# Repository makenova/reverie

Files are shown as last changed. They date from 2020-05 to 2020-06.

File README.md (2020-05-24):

# Reverie
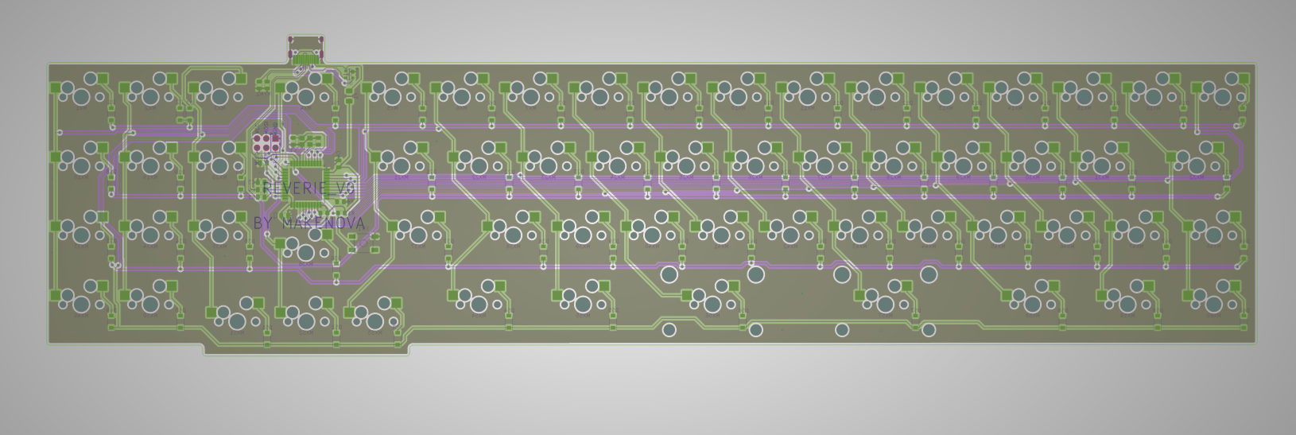
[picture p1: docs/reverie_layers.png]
tracespace back


The reverie is a hot swap mini 1800 inspired by the [Elongate](https://geekhack.org/index.php?topic=106527), [Clarabelle](https://geekhack.org/index.php?topic=106380.0), and [Garbage Truck](https://www.reddit.com/r/MechanicalKeyboards/comments/gkb4nt/the_garbage_truck/) keyboards.
I made this because hot swap is usually left out in smaller runs of high end coustoms.

The plate file can be found in the [docs](./docs) folder.

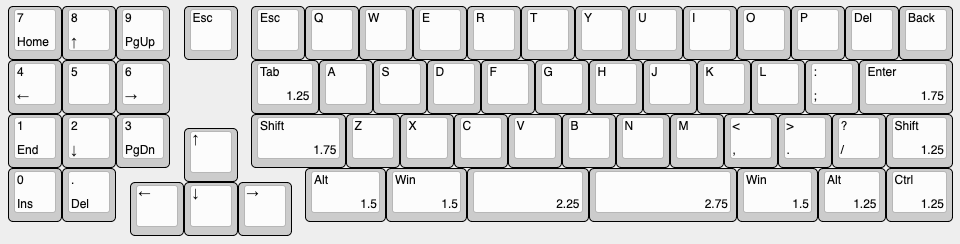
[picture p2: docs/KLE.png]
KLE Diagram


## Wiring Guide

The following diagram displays the colums and rows.

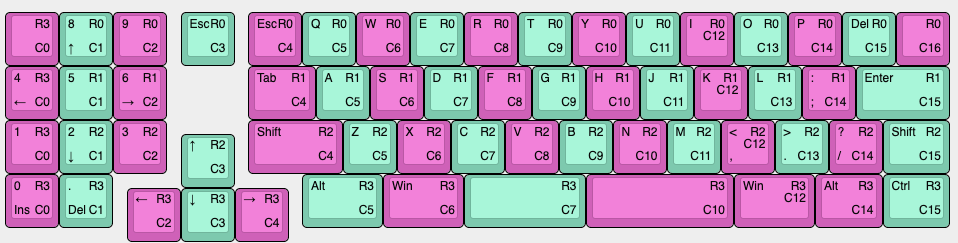
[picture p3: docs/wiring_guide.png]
Wiring Guide


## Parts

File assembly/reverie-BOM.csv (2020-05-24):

Designator | Quantity | Value | Footprint | LCSC Part #
C1, C2, | 2 | 22pF | 0805 | C1804
C3, | 1 | 1uF | 0805 | C28323
C4, C5, C6, | 3 | 0.1uF | 0805 | C49678
C7, | 1 | 10uF | 0805 | C15850
D1, D2, D3, D4, D5, D6, D7, D8, D9, D10, D11, D12, D13, D14, D15, D16, D17, D18, D19, D20, D21, D22, D23, D24, D25, D26, D27, D28, D29, D30, D31, D32, D33, D34, D35, D37, D38, D39, D40, D41, D42, D43, D44, D45, D46, D47, D48, D36, D49, D50, D51, D53, D54, D55, D56, D57, D58, D59, D60, D52, | 60 | D_Small | SOD-123 | C81598
F1, | 1 | Polyfuse_Small | 1206 | C151162
R2, R7, | 2 | 5.1k | 0805 | C27834
R3, R4, | 2 | 22 | 0805 | C17561
R8, R1, | 2 | 10k | 0805 | C17414
SW1, | 1 | SW_Push | :SMD-SW-4_5.1x5.1x1.5 | C318884
U1, | 1 | PRTR5V0U2X | :SOT-143 | C78442
U2, | 1 | ATmega32U4-AU | QFP-44_10.0x10.0x0.8P | C44854
Y1, | 1 | 16MHz | SMD-3225_4P | C13738

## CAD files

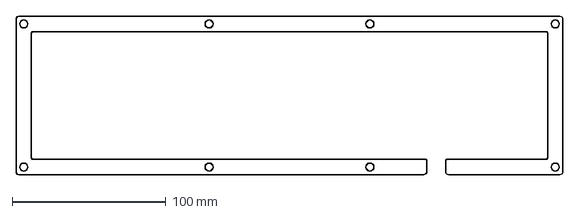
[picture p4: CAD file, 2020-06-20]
case/layer6.dxf
355.4 x 103.0 mm

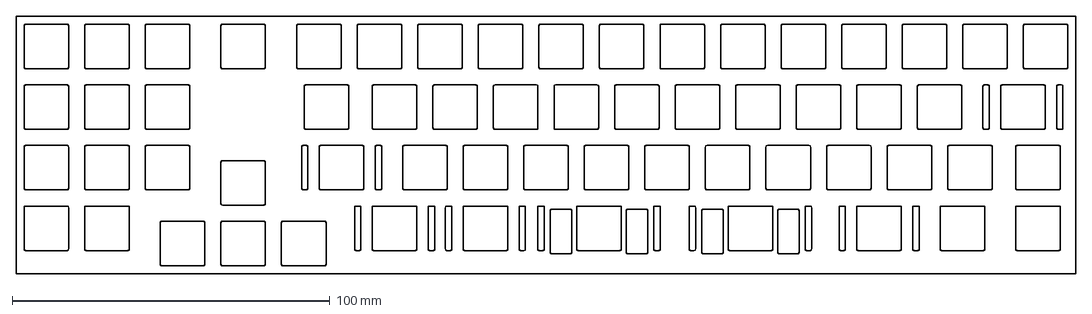
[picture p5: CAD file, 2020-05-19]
docs/plate-20200518-191525.dxf
333.4 x 81.0 mm

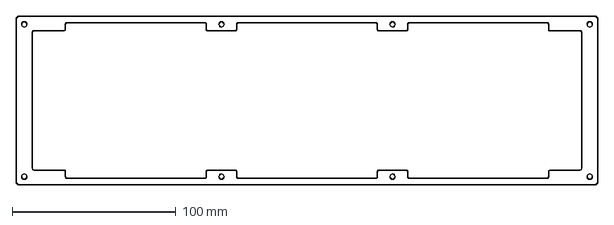
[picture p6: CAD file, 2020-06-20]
case/layer3.dxf
355.4 x 103.0 mm

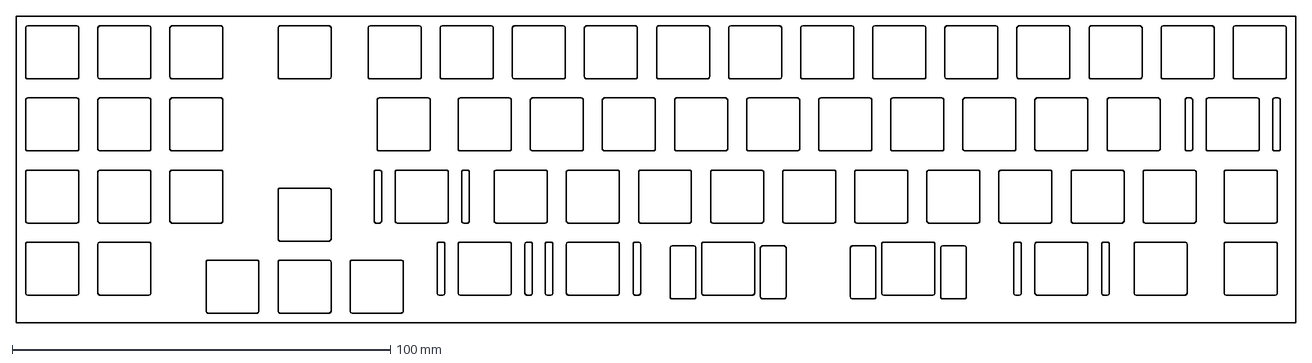
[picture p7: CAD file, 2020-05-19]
docs/plate-20200517-042934.dxf
338.1 x 81.0 mm

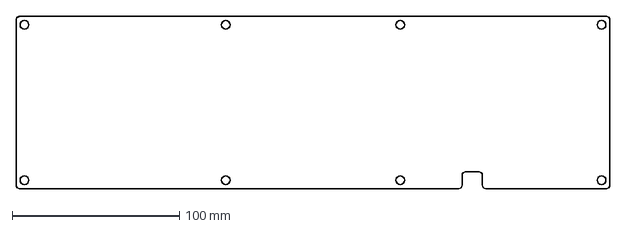
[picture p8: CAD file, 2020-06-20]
case/layer7.dxf
355.4 x 103.0 mm

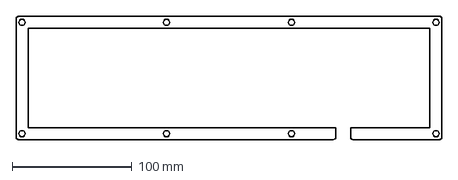
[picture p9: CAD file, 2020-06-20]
case/layer5.dxf
355.4 x 103.0 mm

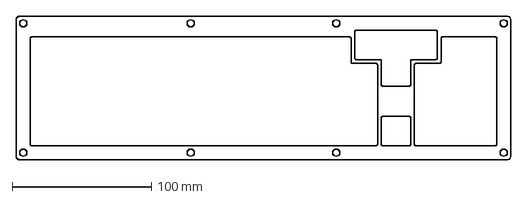
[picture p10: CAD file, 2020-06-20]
case/layer1.dxf
355.4 x 103.0 mm

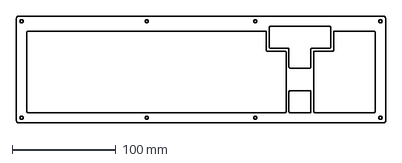
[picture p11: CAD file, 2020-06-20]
case/layer2.dxf
355.4 x 103.0 mm

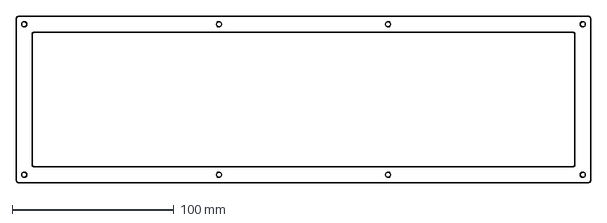
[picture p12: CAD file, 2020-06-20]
case/layer4.dxf
355.4 x 103.0 mm

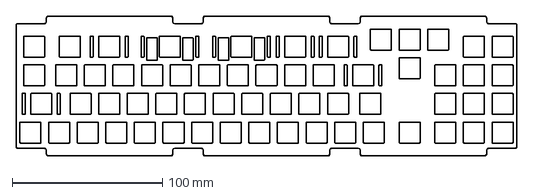
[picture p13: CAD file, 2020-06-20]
case/plate.dxf
333.4 x 93.1 mm

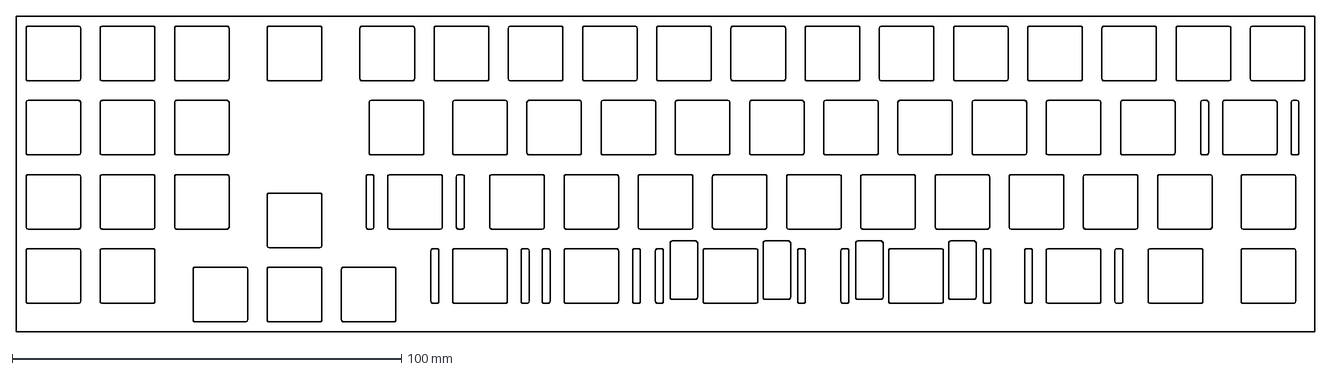
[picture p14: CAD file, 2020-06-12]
case/plate-20200612-134634.dxf
333.4 x 81.0 mm

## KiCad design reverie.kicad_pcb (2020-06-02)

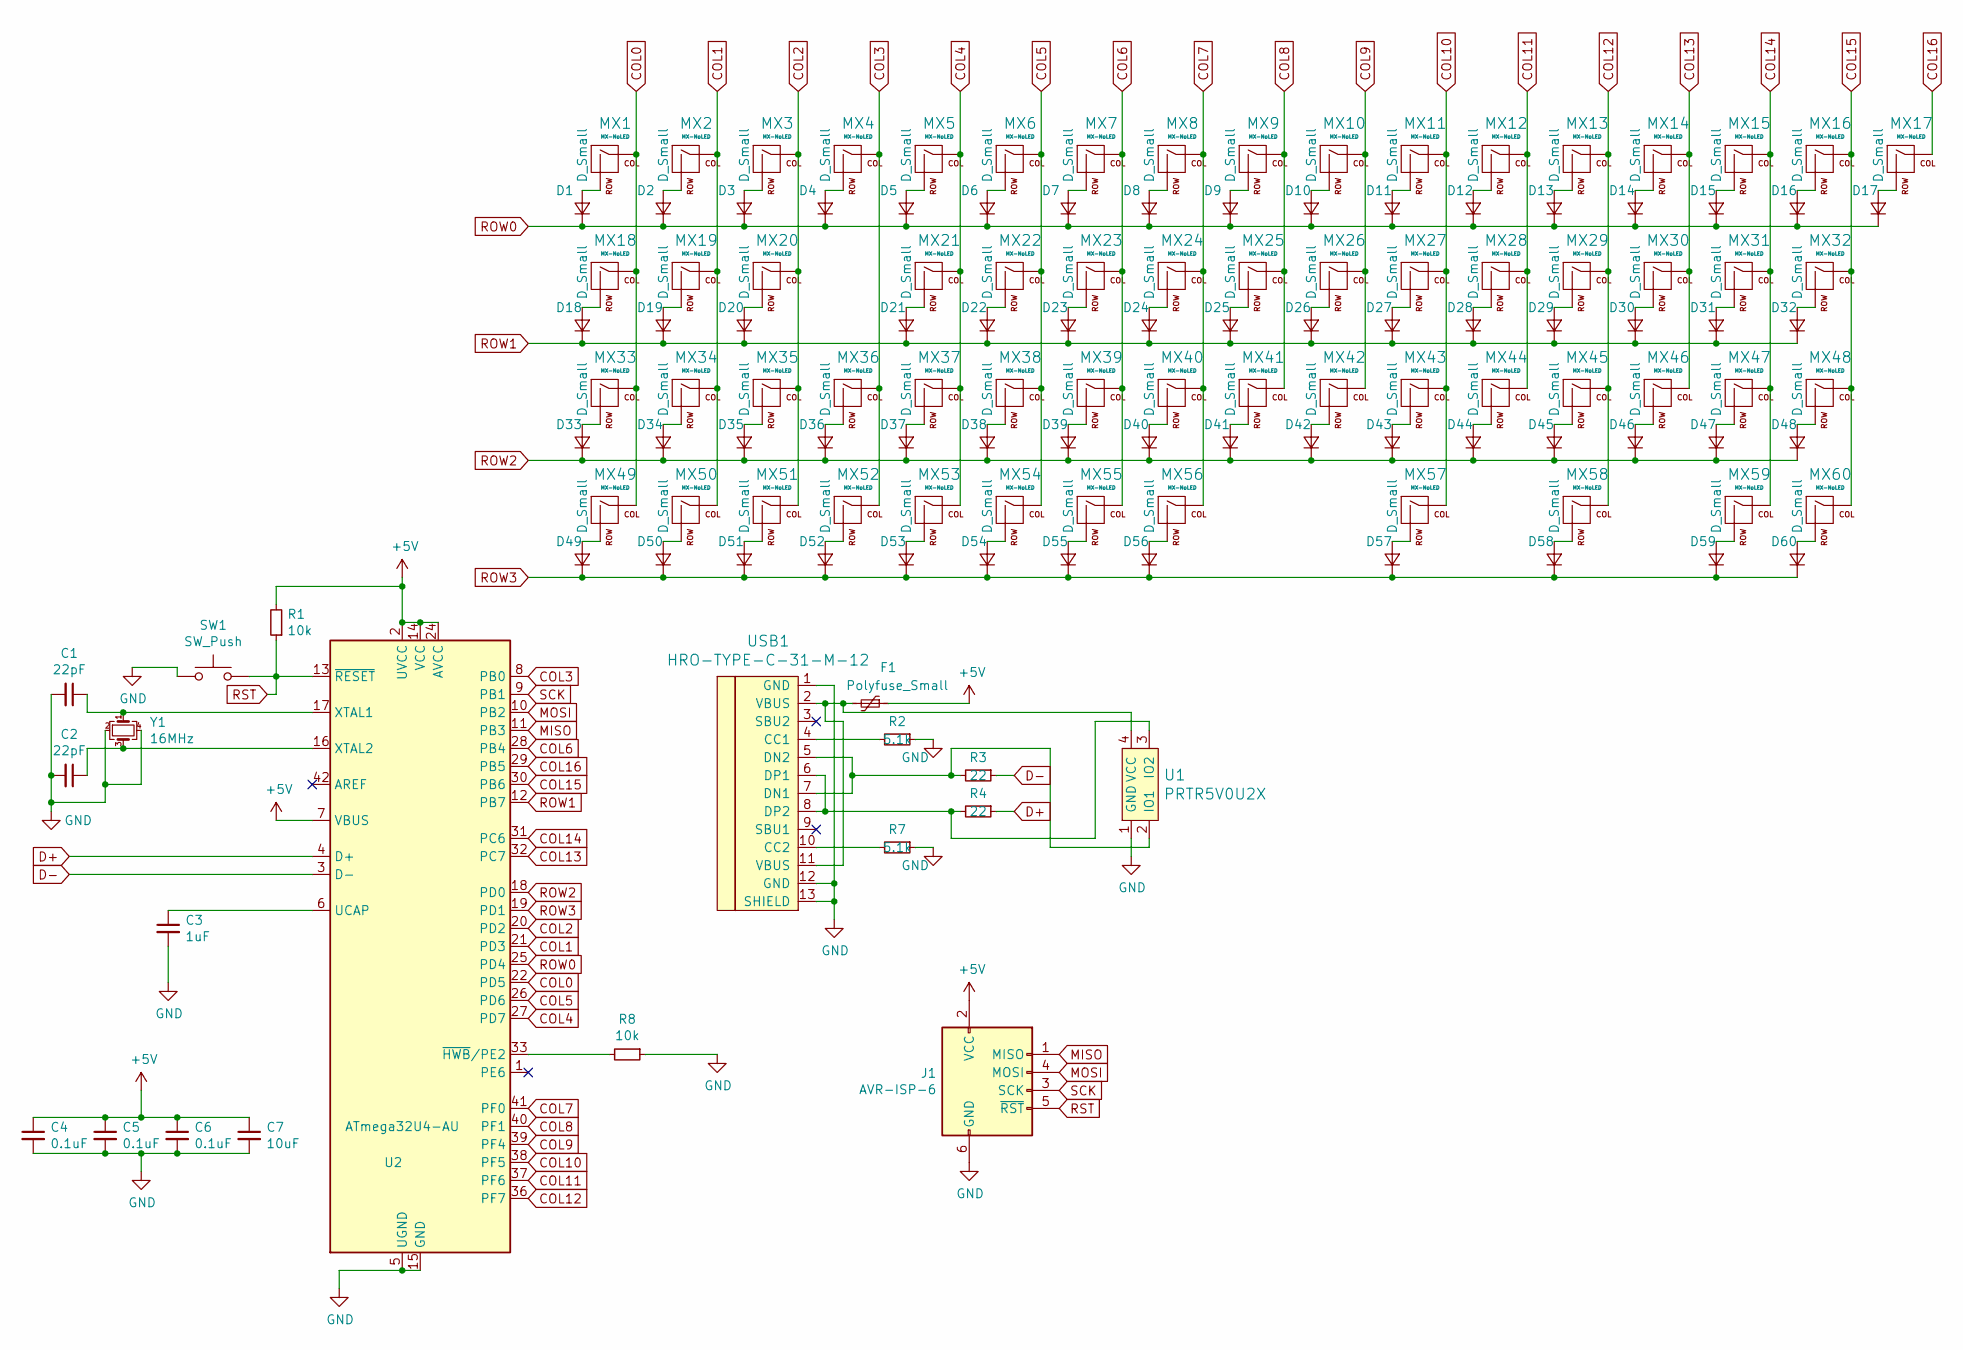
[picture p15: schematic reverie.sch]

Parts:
C1, C2: 22pF; C_0805_2012Metric
C3: 1uF; C_0805_2012Metric
C4, C5, C6: 0.1uF; C_0805_2012Metric
C7: 10uF; C_0805_2012Metric
D1, D2, D3, D4, D5, D6, D7, D8, D9, D10, D11, D12, D13, D14, D15, D16, D17, D18, D19, D20, D21, D22, D23, D24, D25, D26, D27, D28, D29, D30, D31, D32, D33, D34, D35, D36, D37, D38, D39, D40, D41, D42, D43, D44, D45, D46, D47, D48, D49, D50, D51, D52, D53, D54, D55, D56, D57, D58, D59, D60: D_Small; D_SOD-123
F1: Polyfuse_Small; Fuse_1206_3216Metric
J1: AVR-ISP-6; Reset_Pretty-Mask
MX1, MX2, MX3, MX4, MX5, MX6, MX7, MX8, MX9, MX10, MX11, MX12, MX13, MX14, MX15, MX16, MX17, MX18, MX19, MX20, MX22, MX23, MX24, MX25, MX26, MX27, MX28, MX29, MX30, MX31, MX33, MX34, MX35, MX36, MX38, MX39, MX40, MX41, MX42, MX43, MX44, MX45, MX46, MX47, MX49, MX50, MX51, MX52, MX53: MX-NoLED; MXOnly-1U-Hotswap
MX21, MX48, MX59, MX60: MX-NoLED; MXOnly-1.25U-Hotswap
MX32, MX37: MX-NoLED; MXOnly-1.75U-Hotswap
MX54, MX55, MX58: MX-NoLED; MXOnly-1.5U-Hotswap
MX56: MX-NoLED; MXOnly-2.25U-Hotswap-ReversedStabilizers
MX57: MX-NoLED; MXOnly-2.75U-Hotswap-ReversedStabilizers
R1, R8: 10k; R_0805_2012Metric
R2, R7: 5.1k; R_0805_2012Metric
R3, R4: 22; R_0805_2012Metric
SW1: SW_Push; SKQG-1155865
U1: PRTR5V0U2X; SOT143B
U2: ATmega32U4-AU; TQFP-44_10x10mm_P0.8mm
USB1: HRO-TYPE-C-31-M-12; HRO-TYPE-C-31-M-12-HandSoldering
Y1: 16MHz; Crystal_SMD_3225-4Pin_3.2x2.5mm

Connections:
+5V: C4.1, C5.1, C6.1, C7.1, F1.1, J1.2 (VCC), R1.2, U2.2 (UVCC), U2.7 (VBUS), U2.14 (VCC), U2.24 (AVCC), U2.34 (VCC), U2.44 (AVCC)
COL0: MX1.1 (COL), MX18.1 (COL), MX33.1 (COL), MX49.1 (COL), U2.22 (PD5)
COL1: MX2.1 (COL), MX19.1 (COL), MX34.1 (COL), MX50.1 (COL), U2.21 (PD3)
COL2: MX3.1 (COL), MX20.1 (COL), MX35.1 (COL), MX51.1 (COL), U2.20 (PD2)
COL3: MX4.1 (COL), MX36.1 (COL), MX52.1 (COL), U2.8 (PB0)
COL4: MX5.1 (COL), MX21.1 (COL), MX37.1 (COL), MX53.1 (COL), U2.27 (PD7)
COL5: MX6.1 (COL), MX22.1 (COL), MX38.1 (COL), MX54.1 (COL), U2.26 (PD6)
COL6: MX7.1 (COL), MX23.1 (COL), MX39.1 (COL), MX55.1 (COL), U2.28 (PB4)
COL7: MX8.1 (COL), MX24.1 (COL), MX40.1 (COL), MX56.1 (COL), U2.41 (PF0)
COL8: MX9.1 (COL), MX25.1 (COL), MX41.1 (COL), U2.40 (PF1)
COL9: MX10.1 (COL), MX26.1 (COL), MX42.1 (COL), U2.39 (PF4)
COL10: MX11.1 (COL), MX27.1 (COL), MX43.1 (COL), MX57.1 (COL), U2.38 (PF5)
COL11: MX12.1 (COL), MX28.1 (COL), MX44.1 (COL), U2.37 (PF6)
COL12: MX13.1 (COL), MX29.1 (COL), MX45.1 (COL), MX58.1 (COL), U2.36 (PF7)
COL13: MX14.1 (COL), MX30.1 (COL), MX46.1 (COL), U2.32 (PC7)
COL14: MX15.1 (COL), MX31.1 (COL), MX47.1 (COL), MX59.1 (COL), U2.31 (PC6)
COL15: MX16.1 (COL), MX32.1 (COL), MX48.1 (COL), MX60.1 (COL), U2.30 (PB6)
COL16: MX17.1 (COL), U2.29 (PB5)
D+: R4.1, U2.4 (D+)
D-: R3.1, U2.3 (D-)
GND: C1.2, C2.2, C3.2, C4.2, C5.2, C6.2, C7.2, J1.6 (GND), R2.1, R7.1, R8.1, SW1.1, U1.1 (GND), U2.5 (UGND), U2.15 (GND), U2.23 (GND), U2.35 (GND), U2.43 (GND), USB1.1 (GND), USB1.12 (GND), USB1.13 (SHIELD), Y1.2, Y1.4
MISO: J1.1 (MISO), U2.11 (PB3)
MOSI: J1.4 (MOSI), U2.10 (PB2)
unnamed: C1.1, U2.17 (XTAL1), Y1.1
unnamed: C2.1, U2.16 (XTAL2), Y1.3
unnamed: C3.1, U2.6 (UCAP)
unnamed: D1.2 (A), MX1.2 (ROW)
unnamed: D2.2 (A), MX2.2 (ROW)
unnamed: D3.2 (A), MX3.2 (ROW)
unnamed: D4.2 (A), MX4.2 (ROW)
unnamed: D5.2 (A), MX5.2 (ROW)
unnamed: D6.2 (A), MX6.2 (ROW)
unnamed: D7.2 (A), MX7.2 (ROW)
unnamed: D8.2 (A), MX8.2 (ROW)
unnamed: D9.2 (A), MX9.2 (ROW)
unnamed: D10.2 (A), MX10.2 (ROW)
unnamed: D11.2 (A), MX11.2 (ROW)
unnamed: D12.2 (A), MX12.2 (ROW)
unnamed: D13.2 (A), MX13.2 (ROW)
unnamed: D14.2 (A), MX14.2 (ROW)
unnamed: D15.2 (A), MX15.2 (ROW)
unnamed: D16.2 (A), MX16.2 (ROW)
unnamed: D17.2 (A), MX17.2 (ROW)
unnamed: D18.2 (A), MX18.2 (ROW)
unnamed: D19.2 (A), MX19.2 (ROW)
unnamed: D20.2 (A), MX20.2 (ROW)
unnamed: D21.2 (A), MX21.2 (ROW)
unnamed: D22.2 (A), MX22.2 (ROW)
unnamed: D23.2 (A), MX23.2 (ROW)
unnamed: D24.2 (A), MX24.2 (ROW)
unnamed: D25.2 (A), MX25.2 (ROW)
unnamed: D26.2 (A), MX26.2 (ROW)
unnamed: D27.2 (A), MX27.2 (ROW)
unnamed: D28.2 (A), MX28.2 (ROW)
unnamed: D29.2 (A), MX29.2 (ROW)
unnamed: D30.2 (A), MX30.2 (ROW)
unnamed: D31.2 (A), MX31.2 (ROW)
unnamed: D32.2 (A), MX32.2 (ROW)
unnamed: D33.2 (A), MX33.2 (ROW)
unnamed: D34.2 (A), MX34.2 (ROW)
unnamed: D35.2 (A), MX35.2 (ROW)
unnamed: D36.2 (A), MX36.2 (ROW)
unnamed: D37.2 (A), MX37.2 (ROW)
unnamed: D38.2 (A), MX38.2 (ROW)
unnamed: D39.2 (A), MX39.2 (ROW)
unnamed: D40.2 (A), MX40.2 (ROW)
unnamed: D41.2 (A), MX41.2 (ROW)
unnamed: D42.2 (A), MX42.2 (ROW)
unnamed: D43.2 (A), MX43.2 (ROW)
unnamed: D44.2 (A), MX44.2 (ROW)
unnamed: D45.2 (A), MX45.2 (ROW)
unnamed: D46.2 (A), MX46.2 (ROW)
unnamed: D47.2 (A), MX47.2 (ROW)
unnamed: D48.2 (A), MX48.2 (ROW)
unnamed: D49.2 (A), MX49.2 (ROW)
unnamed: D50.2 (A), MX50.2 (ROW)
unnamed: D51.2 (A), MX51.2 (ROW)
unnamed: D52.2 (A), MX52.2 (ROW)
unnamed: D53.2 (A), MX53.2 (ROW)
unnamed: D54.2 (A), MX54.2 (ROW)
unnamed: D55.2 (A), MX55.2 (ROW)
unnamed: D56.2 (A), MX56.2 (ROW)
unnamed: D57.2 (A), MX57.2 (ROW)
unnamed: D58.2 (A), MX58.2 (ROW)
unnamed: D59.2 (A), MX59.2 (ROW)
unnamed: D60.2 (A), MX60.2 (ROW)
unnamed: F1.2, U1.4 (VCC), USB1.2 (VBUS), USB1.11 (VBUS)
unnamed: R2.2, USB1.4 (CC1)
unnamed: R3.2, U1.2 (IO1), USB1.5 (DN2), USB1.7 (DN1)
unnamed: R4.2, U1.3 (IO2), USB1.6 (DP1), USB1.8 (DP2)
unnamed: R7.2, USB1.10 (CC2)
unnamed: R8.2, U2.33 (~HWB~/PE2)
ROW0: D1.1 (K), D2.1 (K), D3.1 (K), D4.1 (K), D5.1 (K), D6.1 (K), D7.1 (K), D8.1 (K), D9.1 (K), D10.1 (K), D11.1 (K), D12.1 (K), D13.1 (K), D14.1 (K), D15.1 (K), D16.1 (K), D17.1 (K), U2.25 (PD4)
ROW1: D18.1 (K), D19.1 (K), D20.1 (K), D21.1 (K), D22.1 (K), D23.1 (K), D24.1 (K), D25.1 (K), D26.1 (K), D27.1 (K), D28.1 (K), D29.1 (K), D30.1 (K), D31.1 (K), D32.1 (K), U2.12 (PB7)
ROW2: D33.1 (K), D34.1 (K), D35.1 (K), D36.1 (K), D37.1 (K), D38.1 (K), D39.1 (K), D40.1 (K), D41.1 (K), D42.1 (K), D43.1 (K), D44.1 (K), D45.1 (K), D46.1 (K), D47.1 (K), D48.1 (K), U2.18 (PD0)
ROW3: D49.1 (K), D50.1 (K), D51.1 (K), D52.1 (K), D53.1 (K), D54.1 (K), D55.1 (K), D56.1 (K), D57.1 (K), D58.1 (K), D59.1 (K), D60.1 (K), U2.19 (PD1)
RST: J1.5 (~RST), R1.1, SW1.2, U2.13 (~RESET)
SCK: J1.3 (SCK), U2.9 (PB1)

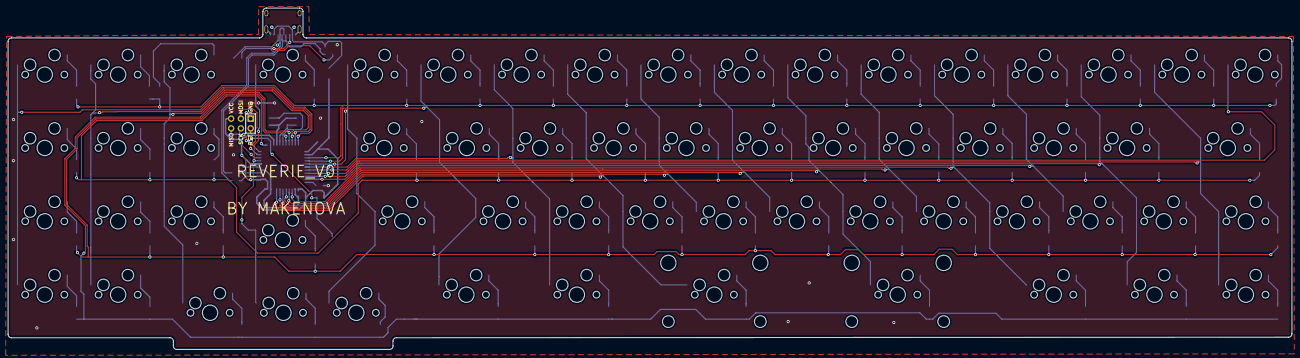
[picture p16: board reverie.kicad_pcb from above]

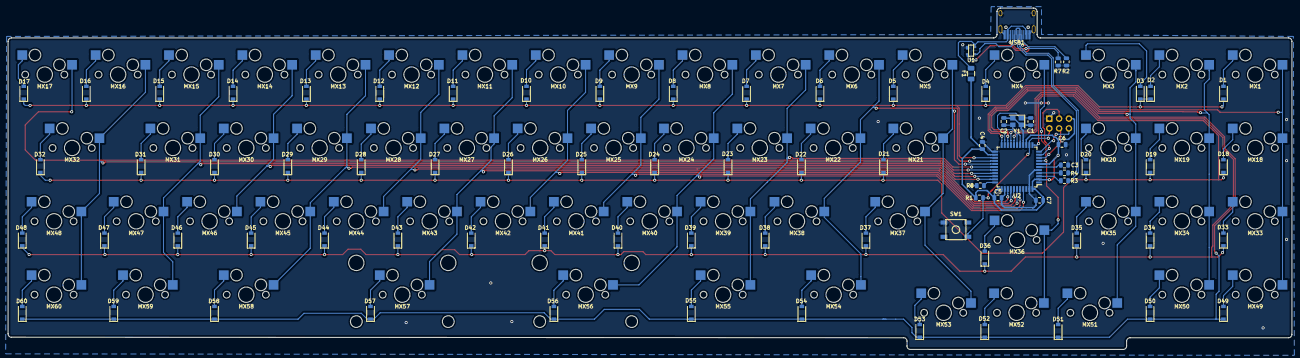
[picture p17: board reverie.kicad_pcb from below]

Board: 2 copper layers, 333.4 x 88.6 mm, 140 parts (79 on the bottom side), 98 nets.

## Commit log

2020-05-18 make it so
    add libraries and footprints to schematic and pcb in project specific libraries
    [reverie.kicad_pcb, reverie.sch]
2020-05-18 wire up the mcu
    [reverie.sch]
2020-05-19 update schematic
    add swtich matrix, usb, and esd circuits
    assign footprints
    [reverie.sch]
2020-05-19 add readme
    add KLE diagram
    add wiring guide diagram
    add plate file
    [plate-20200517-042934.dxf]
2020-05-19 align diodes on pcb
    [plate-20200518-191525.dxf, reverie.sch]
2020-05-21 initial layout and routing
    [reverie.kicad_pcb, reverie.sch]
2020-05-24 complete routing
    add ISP programmer
    [reverie.kicad_pcb, reverie.sch]
2020-05-24 clean up
    [reverie.kicad_pcb, reverie.sch]
2020-05-24 add vanity silk text
    [reverie.kicad_pcb]
2020-05-24 generate production files
    BOM
    Placement files
    gerbers
    [reverie-BOM.csv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]
2020-05-24 add tracespace files
2020-05-24 reshape edge cuts
    regenerate gerber drill files and tracespace
    [reverie-B_Cu.gbr, reverie-B_Mask.gbr, reverie-B_SilkS.gbr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]
2020-06-02 work on edgecuts and replace isp footprint
    [reverie-B_Cu.gbr, reverie-B_Mask.gbr, reverie-B_SilkS.gbr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]
2020-06-12 reverse stabilizers on plate
    [plate-20200612-134634.dxf]
2020-06-15 case stuff
    [layer1.dxf, layer2.dxf, layer3.dxf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]
2020-06-20 export reverie plate
    [layer1.dxf, layer2.dxf, layer3.dxf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]
